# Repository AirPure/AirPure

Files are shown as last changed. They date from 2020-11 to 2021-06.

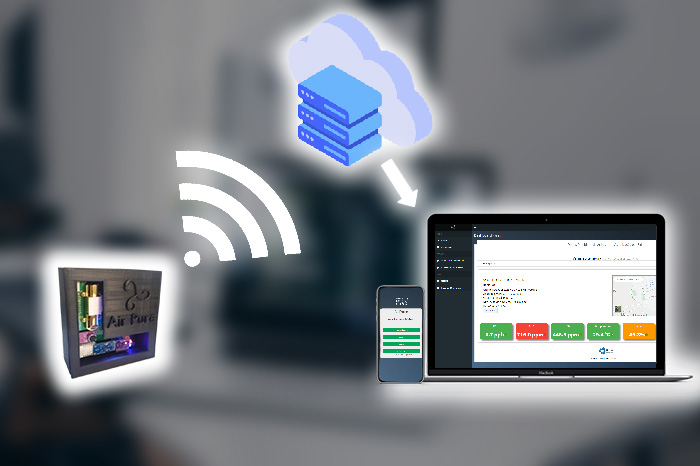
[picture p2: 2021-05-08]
Landing Page/assets/img/landing2.jpg

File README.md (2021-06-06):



[AirPure](https://sites.google.com/view/airpure/pagina-inicial?authuser=0) é um sistema embarcado para análise de qualidade do ar.

### Motivação
A qualidade do ar em ambientes internos torna-se uma preocupação em consequência do
aumento de construções de ambientes selados devido à climatização artificial. Apesar da
existência de legislações que exigem o monitoramento e controle da qualidade do ar, em
muitos locais há indícios de que essa prática não é aplicada, demonstrando a necessário
da implantação de um dispositivo que realize esse monitoramento de forma autônoma
e constante. Este trabalho apresenta o Air-pure, uma solução de Internet das Coisas
para o monitoramento da qualidade do ar em ambientes internos, que realiza a leitura
de temperatura, umidade relativa e concentrações de dióxido de carbono e Compostos
Orgânicos Voláteis Totais. A solução é organizada nas seguintes etapas: construção do
dispositivo físico, armazenamento e fusão dos dados na plataforma IoT ThingSpeakTM,
e página Web para apresentação dos dados aos usuários. Experimentos realizados em
ambientes climatizados artificialmente, mostram elevações na concentração de CO2 e
TVOC, que chegam a ultrapassar os limites recomendados. Os dados obtidos comprovam
a importância do monitoramento constante para avaliar situações diversas no ambiente e
a necessidade de ações, como a ventilação adequada, para melhoria da qualidade do ar e
consequentemente a saúde dos ocupantes.

### Tecnologias
* :white_check_mark: MQTT 
* :white_check_mark: IoT 
* :white_check_mark: ThingSpeak 
* :white_check_mark: WiFi 
* :white_check_mark: Over-the-Air Updates 
* :white_check_mark: ESP-NOW 
* :white_check_mark: Home Assistant 
* :white_check_mark: HTTP Protocol 

### Hardware
* :floppy_disk: ESP32 
* :floppy_disk: MHZ-14A 
* :floppy_disk: CCS811 
* :floppy_disk: DHT-22 
* :floppy_disk: MAX-9814 
* :floppy_disk: BH-1750

### Participantes do Projeto
* :bust_in_silhouette: Prof. Dr. Renato Bulcão Neto 
* :bust_in_silhouette: Prof. Dr. Iwens Sene Júnior 
* :bust_in_silhouette: Bruna Michelly  
* :bust_in_silhouette: Melyssa Mariana 
* :bust_in_silhouette: Isabela França 
* :bust_in_silhouette: Lucas Felipe 
* :bust_in_silhouette: Antonio Emílio

### Canais ThingSpeak
Canal 1 (1160801): [Clique Aqui](https://thingspeak.com/channels/1160801)</br>
Canal 2 (1167146): [Clique Aqui](https://thingspeak.com/channels/1167146)</br>
Canal 3 (1177969): [Clique Aqui](https://thingspeak.com/channels/1177969)</br>

### Como visualizar a aplicação
Para visualizar o website, [clique aqui.](https://airpurelanding.vercel.app/)

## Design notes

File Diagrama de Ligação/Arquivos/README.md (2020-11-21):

# AirPure
O AirPure é um sistema embarcado para análise de qualidade do ar.

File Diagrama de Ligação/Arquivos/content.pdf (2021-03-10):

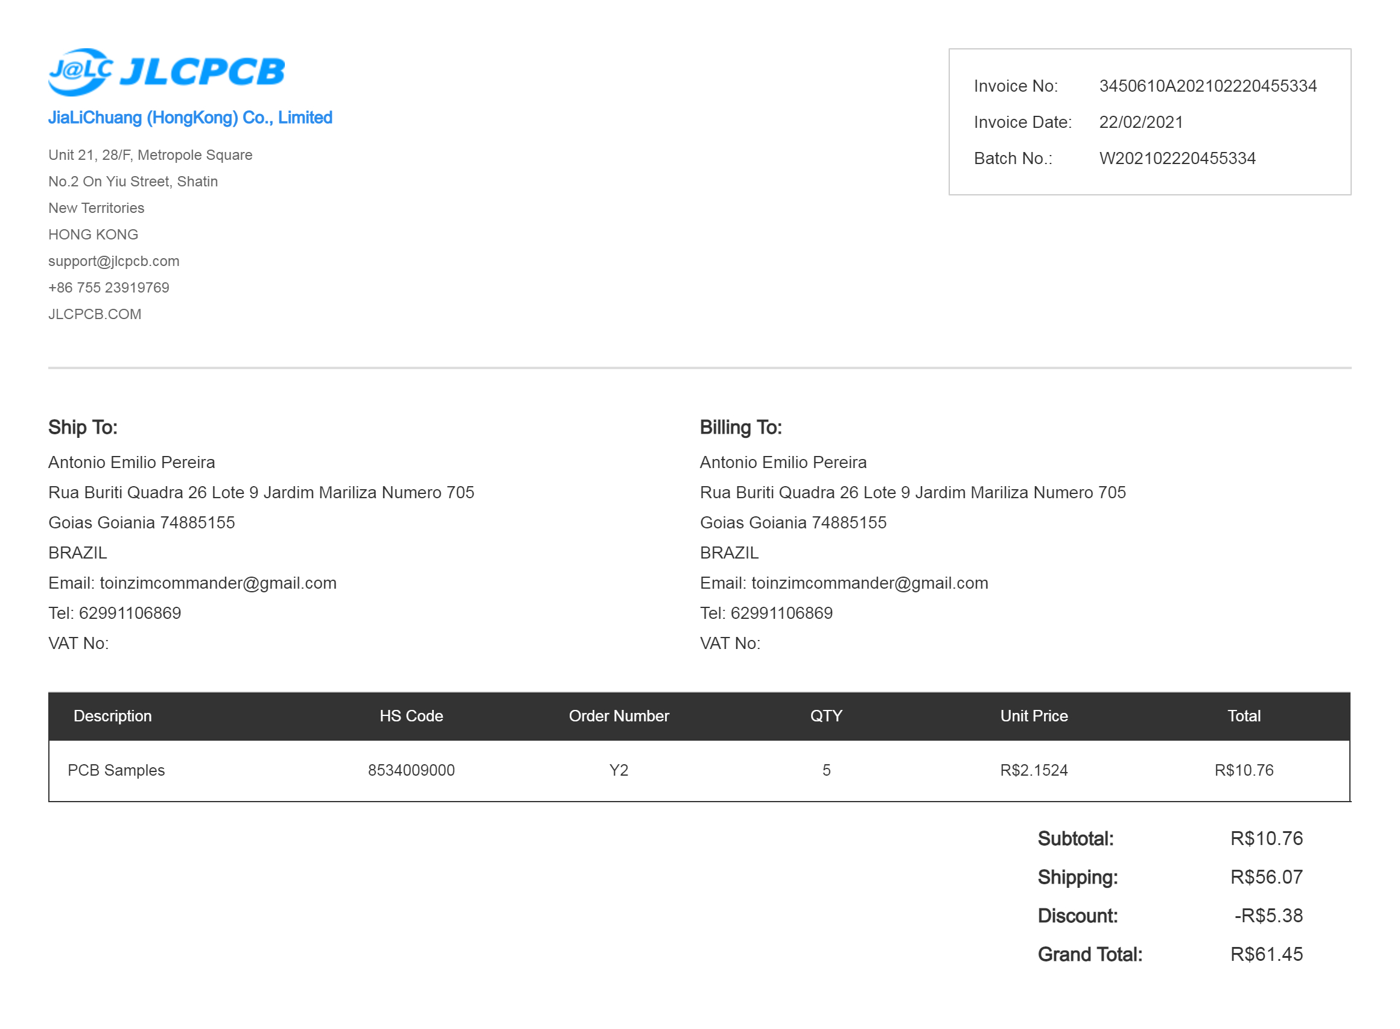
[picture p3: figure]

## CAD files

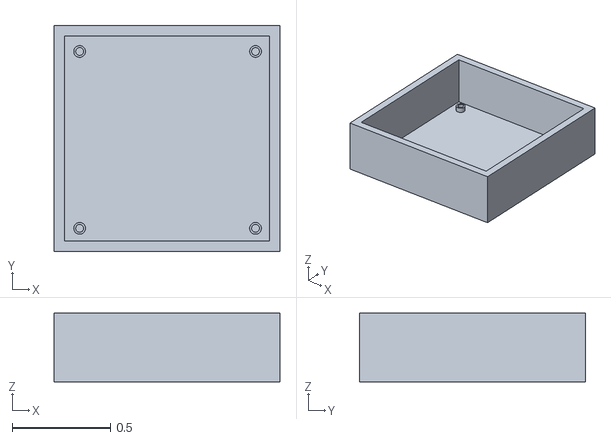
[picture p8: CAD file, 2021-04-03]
Diagrama de Ligação/Arquivos/TESTE23.stl
1.15 x 1.15 x 0.35

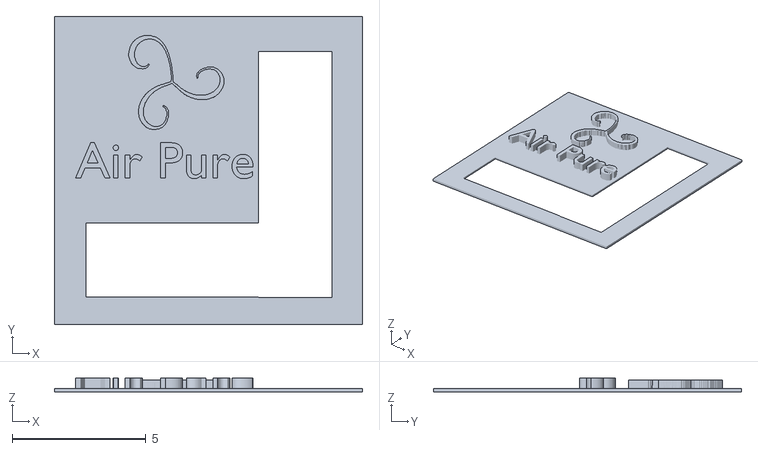
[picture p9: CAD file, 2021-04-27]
Diagrama de Ligação/Tampa.stl
11.5 x 11.5 x 0.515

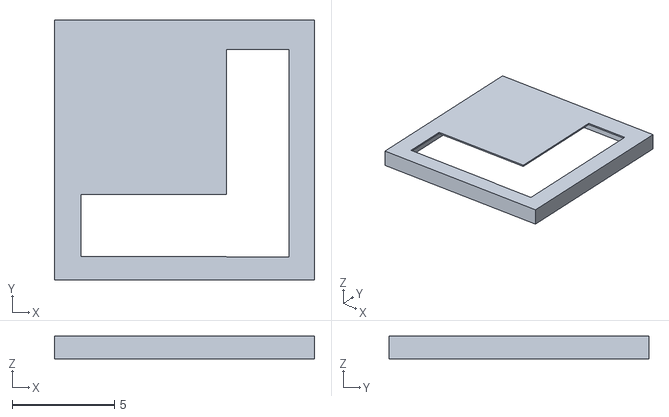
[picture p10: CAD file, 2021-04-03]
Diagrama de Ligação/Arquivos/TAMPASEMLOGO.stl
12.7 x 12.7 x 1.10

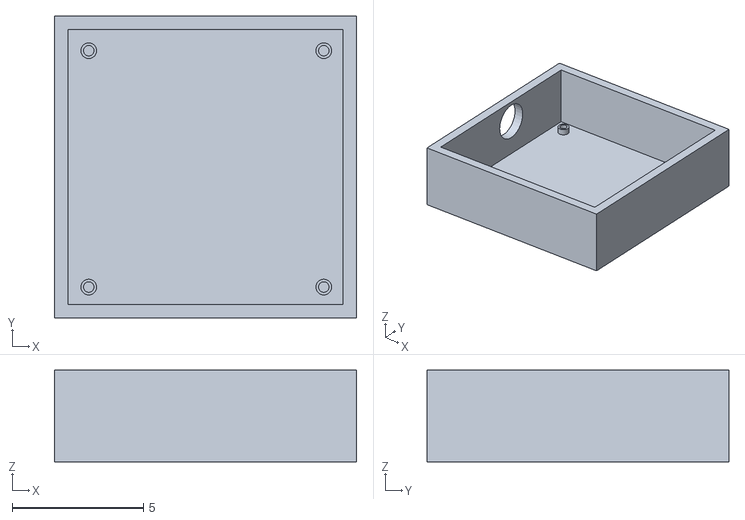
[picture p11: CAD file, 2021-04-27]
Diagrama de Ligação/Base.stl
11.5 x 11.5 x 3.50

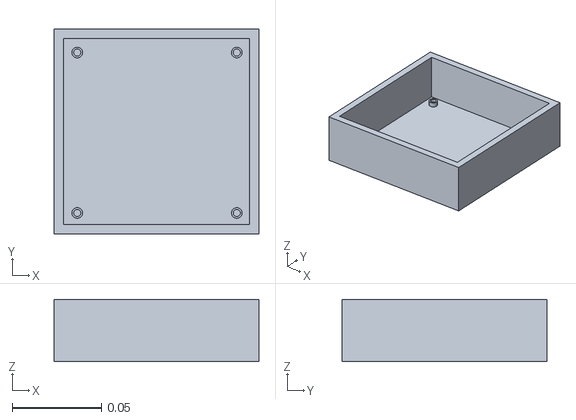
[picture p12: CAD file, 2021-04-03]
Diagrama de Ligação/Arquivos/TESTE1.stl
0.115 x 0.115 x 0.035

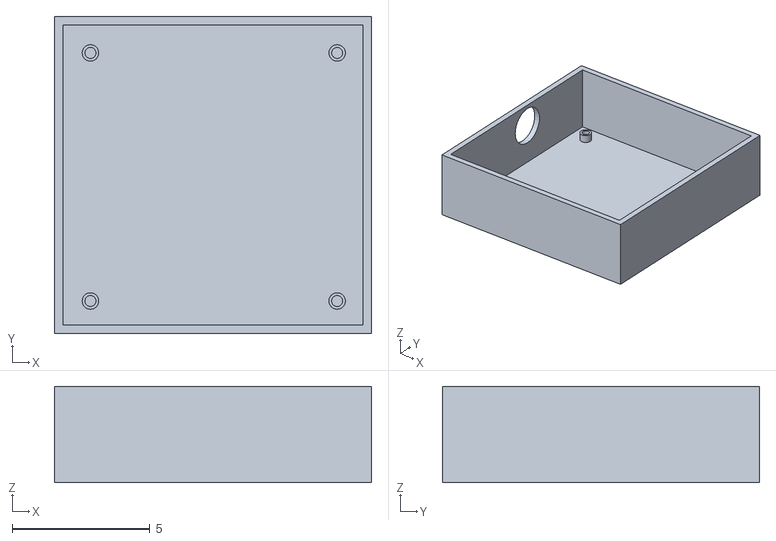
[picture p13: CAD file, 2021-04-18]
Diagrama de Ligação/COMPLETO2.stl
11.5 x 11.5 x 3.50

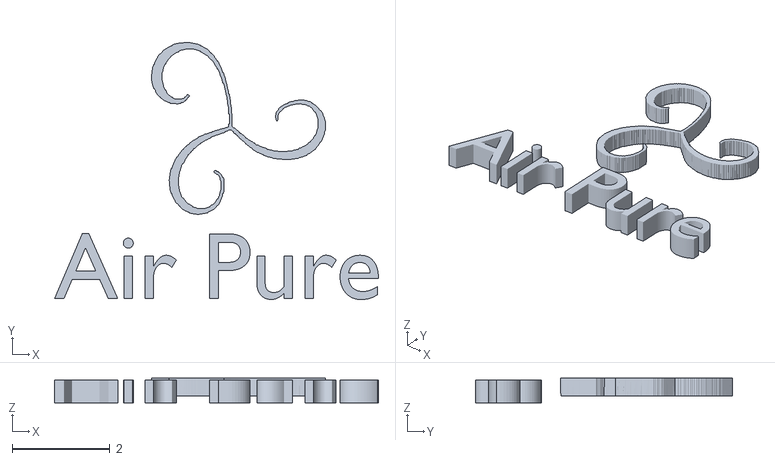
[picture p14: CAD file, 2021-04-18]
Diagrama de Ligação/LOGOAIRPURE.stl
6.63 x 5.26 x 0.511

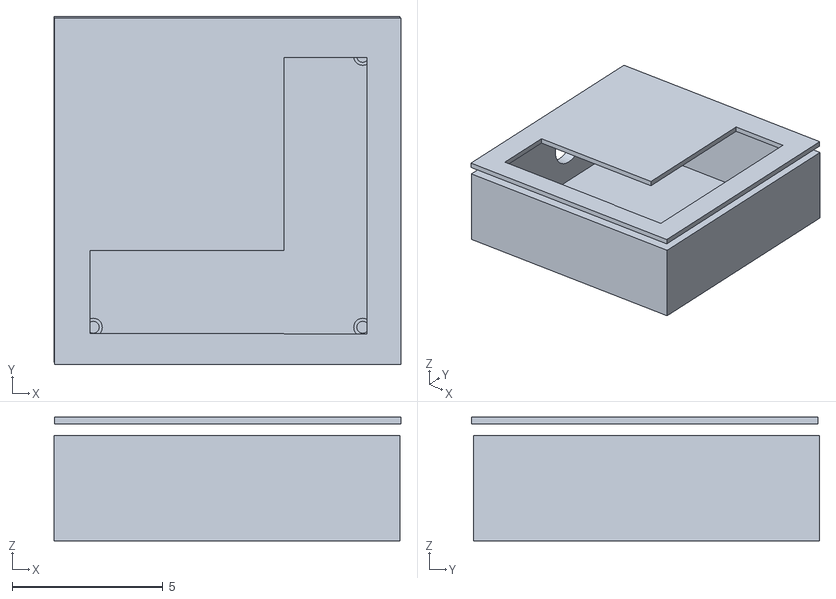
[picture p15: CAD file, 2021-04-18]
Diagrama de Ligação/COMPLETO.stl
11.5 x 11.6 x 4.11

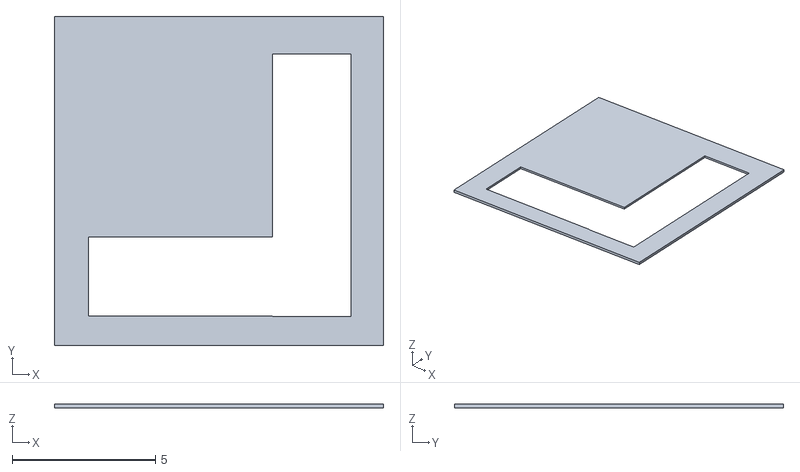
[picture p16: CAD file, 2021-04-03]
Diagrama de Ligação/Arquivos/TAMPASEMLOGO2.stl
11.5 x 11.5 x 0.128

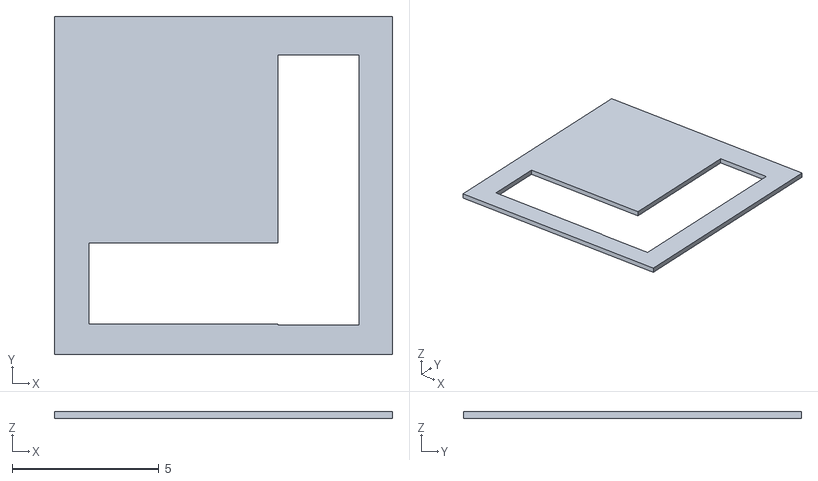
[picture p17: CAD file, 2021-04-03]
Diagrama de Ligação/TAMPA_OK.stl
11.5 x 11.5 x 0.231

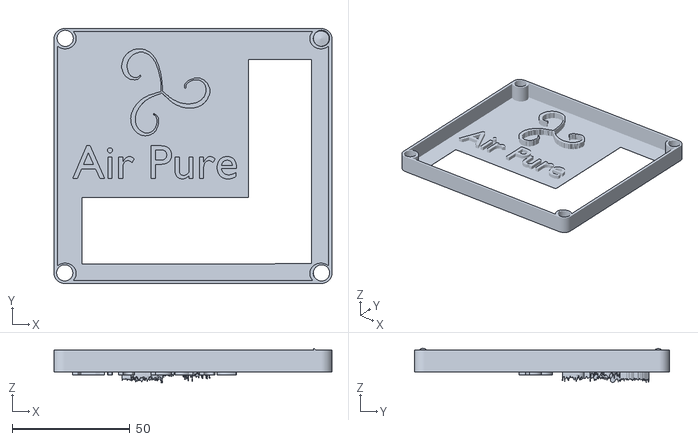
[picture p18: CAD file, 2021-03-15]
Diagrama de Ligação/Arquivos/tampa01.stl
118.2 x 108.5 x 14.7

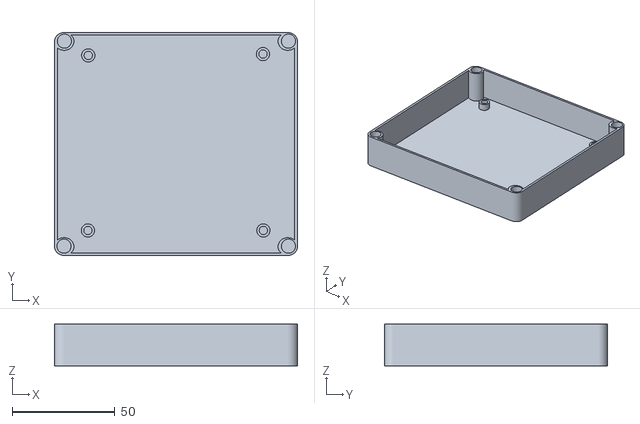
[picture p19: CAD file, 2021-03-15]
Diagrama de Ligação/Arquivos/base01.stl
118.2 x 108.5 x 20.3

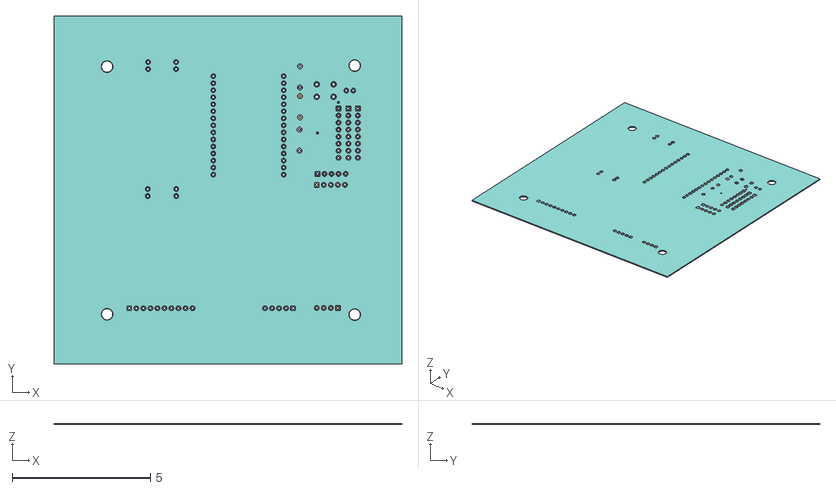
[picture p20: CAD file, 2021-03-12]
Diagrama de Ligação/Arquivos/PCB_AIRPURE_2021-03-10.obj
12.6 x 12.6 x 0.0503
Top
R2
R1
U1
J3
H2
J4
J5
J1
J2
J6
J7
J8
R3
SW1
LED1
IMPORTED_IMAGE
3.3V
SCL
SDA
LED_ESP
VOUT_DHT
TX2
GND
VOUT_MAX
33V
BUTTON
RX2
5V
LED1_2
Solder_Top
Core
Solder_Bottom

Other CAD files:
Diagrama de Ligação/Arquivos/TESTE233.stl
Diagrama de Ligação/Arquivos/BASE_AIRPURE.stl
Diagrama de Ligação/Arquivos/base02.stl
Diagrama de Ligação/Arquivos/OBJ_PCB_AIRPURE.obj
Diagrama de Ligação/Arquivos/OBJ_PCB_AIRPURE.stl
Diagrama de Ligação/Arquivos/PCB_AIRPURE_2021-02-21.dxf
Diagrama de Ligação/Arquivos/airpure_case.blend
Diagrama de Ligação/Arquivos/airpure_case.stl
Diagrama de Ligação/Arquivos/b100x100x25v1.stl
Diagrama de Ligação/Arquivos/hexagon_sheet_3.stl
Diagrama de Ligação/Arquivos/pcb_pcb_airpure_2021-03-10.stl
Diagrama de Ligação/Arquivos/sem título.stl
Diagrama de Ligação/Arquivos/untitled.blend
Diagrama de Ligação/Arquivos/untitled.stl
Diagrama de Ligação/Arquivos/untitledbase.stl
Diagrama de Ligação/FINAL_OK.blend
Diagrama de Ligação/TESTE1.blend

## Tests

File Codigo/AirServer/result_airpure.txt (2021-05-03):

5
5
6
5
10
21
1
1
5
2
3
6
3
1
1
1
1
1
1
1
1
1
1
1
1
1
1
1
1
1
1
1
1
5
5
5
5
5
5
1
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

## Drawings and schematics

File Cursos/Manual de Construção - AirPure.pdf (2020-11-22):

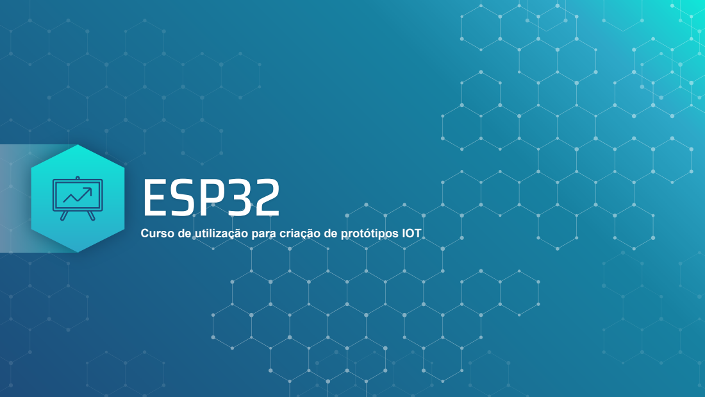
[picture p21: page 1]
ESP32

Curso de utilização para criação de protótipos IOT

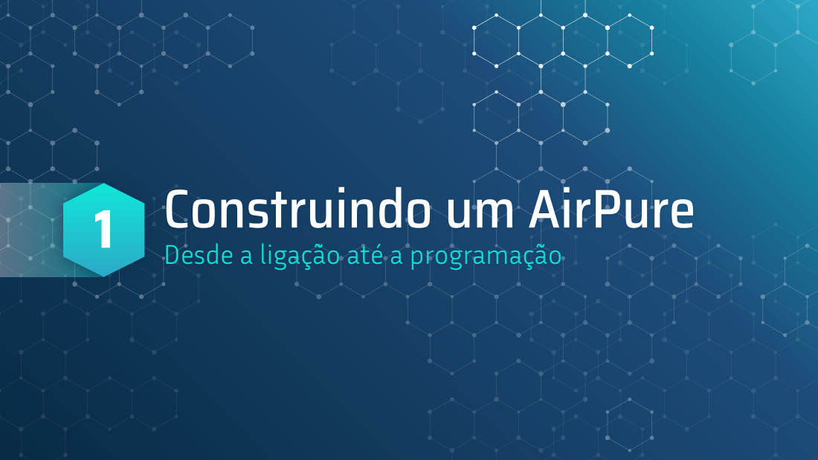
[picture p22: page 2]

Construindo um AirPure
Desde a ligação até a programação 1

# Diagrama de ligações

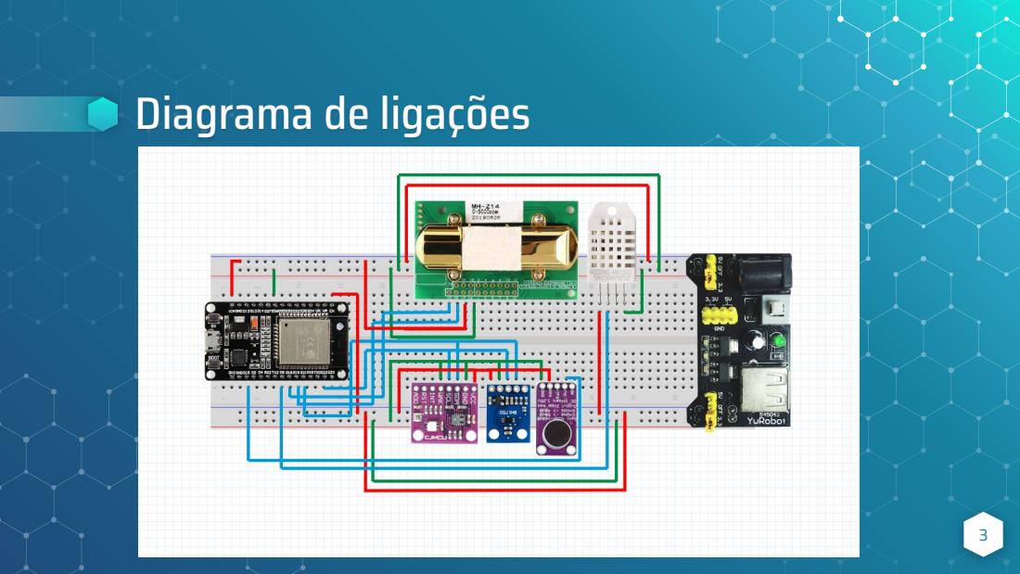
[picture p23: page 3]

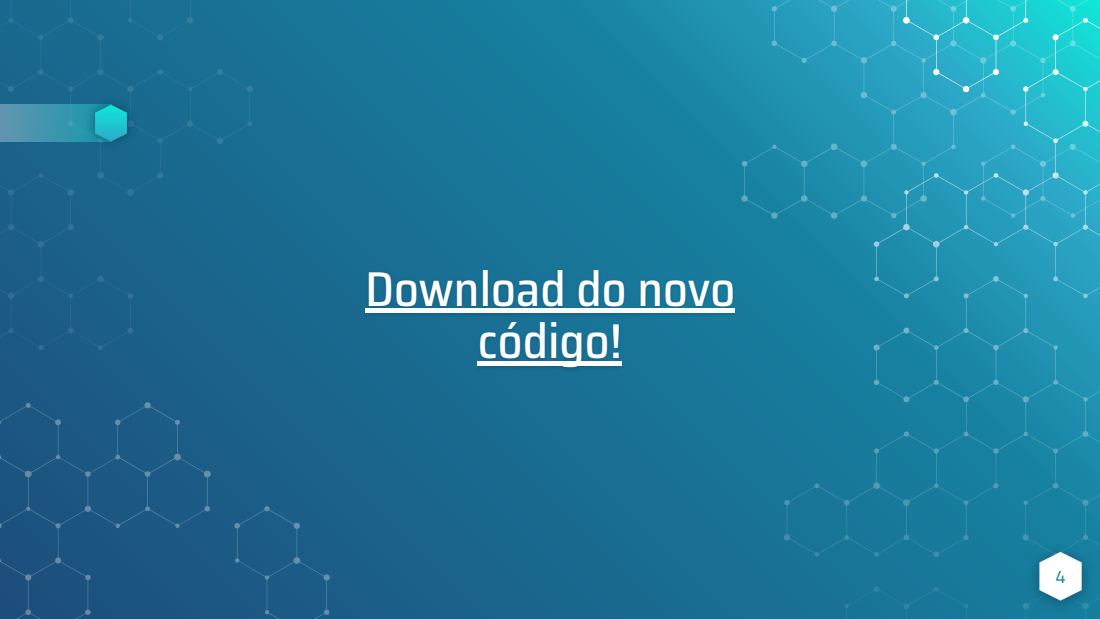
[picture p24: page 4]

Download do novo (https://drive.google.com/file/d/1TJgL_6C4kQ0yvQ0MD830oPwlq83Xvipd/view?usp=sharing)
código! (https://github.com/AirPure/AirPure)

# Bibliotecas necessária

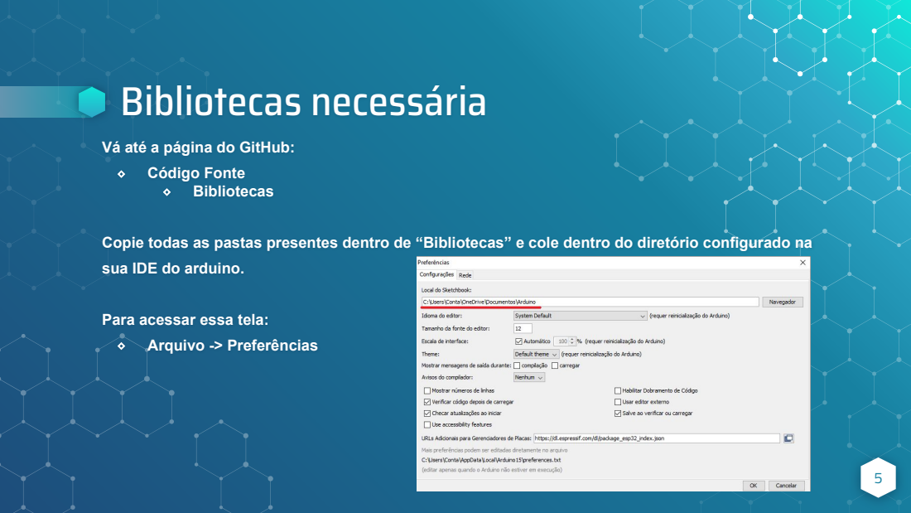
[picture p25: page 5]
Código Fonte; Bibliotecas; Arquivo -> Preferências

Vá até a página do GitHub:

Copie todas as pastas presentes dentro de “Bibliotecas” e cole dentro do diretório configurado na
sua IDE do arduino.

Para acessar essa tela:

# Configurando as credenciais

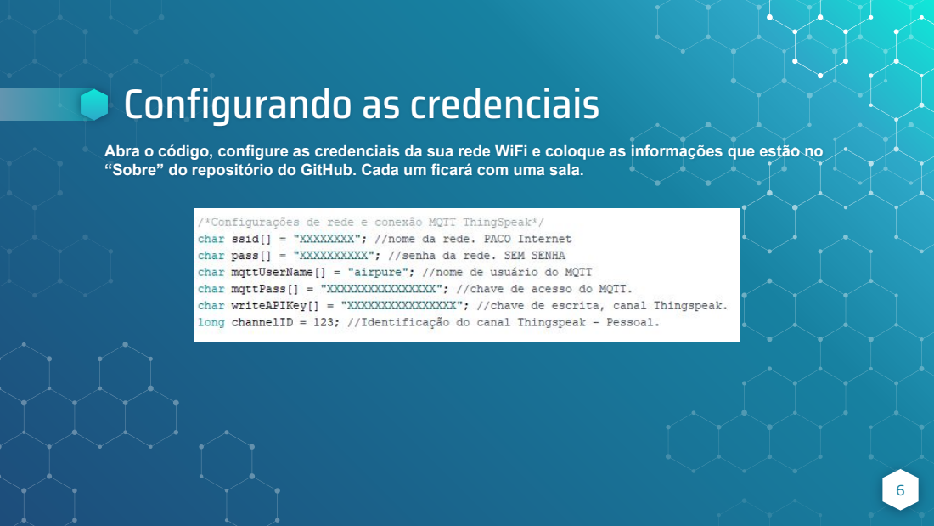
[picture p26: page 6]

Abra o código, configure as credenciais da sua rede WiFi e coloque as informações que estão no
“Sobre” do repositório do GitHub. Cada um ficará com uma sala.

# Grave o código no seu AirPure

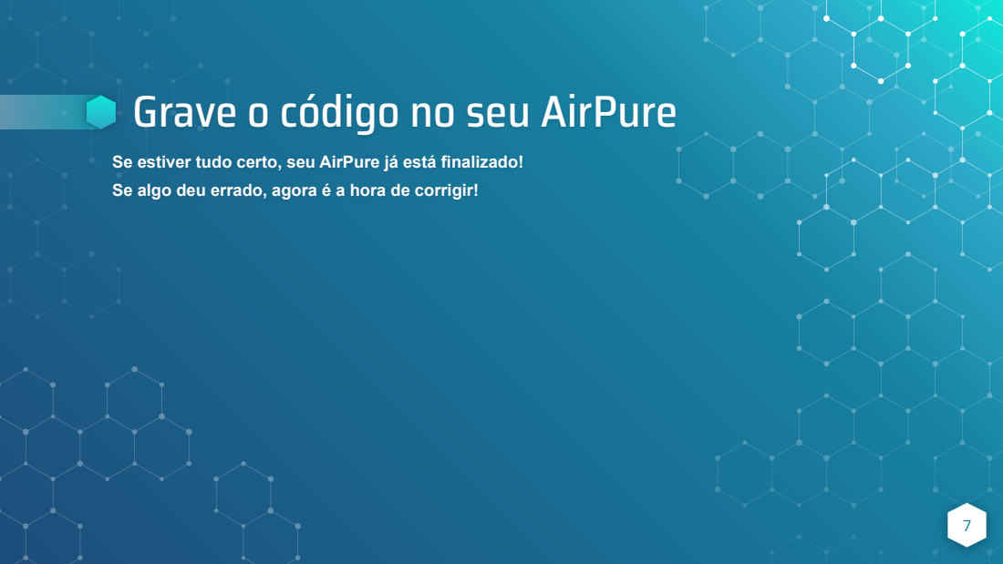
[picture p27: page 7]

Se estiver tudo certo, seu AirPure já está finalizado!
Se algo deu errado, agora é a hora de corrigir!

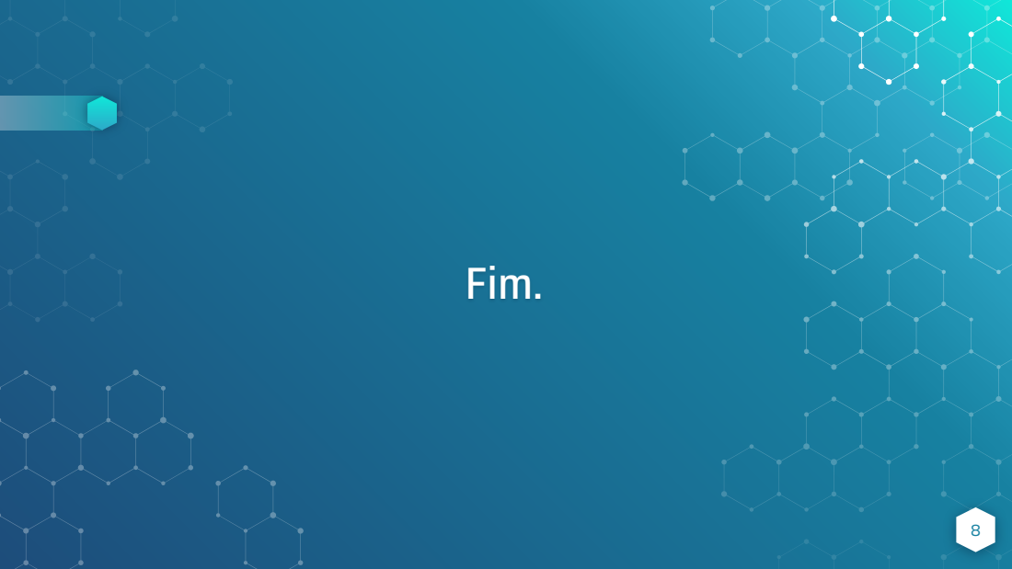
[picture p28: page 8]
Fim.

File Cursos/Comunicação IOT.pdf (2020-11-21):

Melyssa Mariana
melyssa.mariana32@gmail.com
Tecnologias de
comunicação iot:

Da teoria à prática

# IOT x embarcados

1

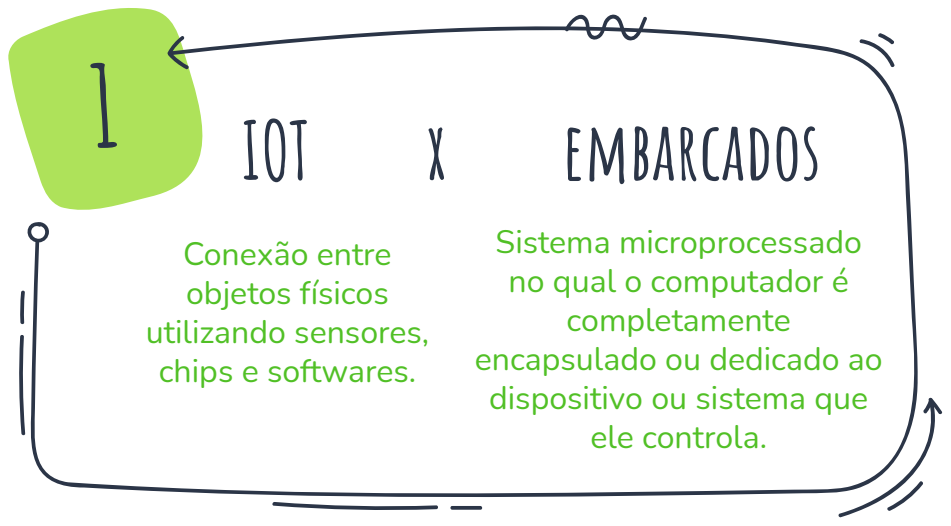
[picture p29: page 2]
Conexão entre objetos físicos utilizando sensores, chips e softwares.

Sistema microprocessado
no qual o computador é
completamente
encapsulado ou dedicado ao
dispositivo ou sistema que
ele controla.

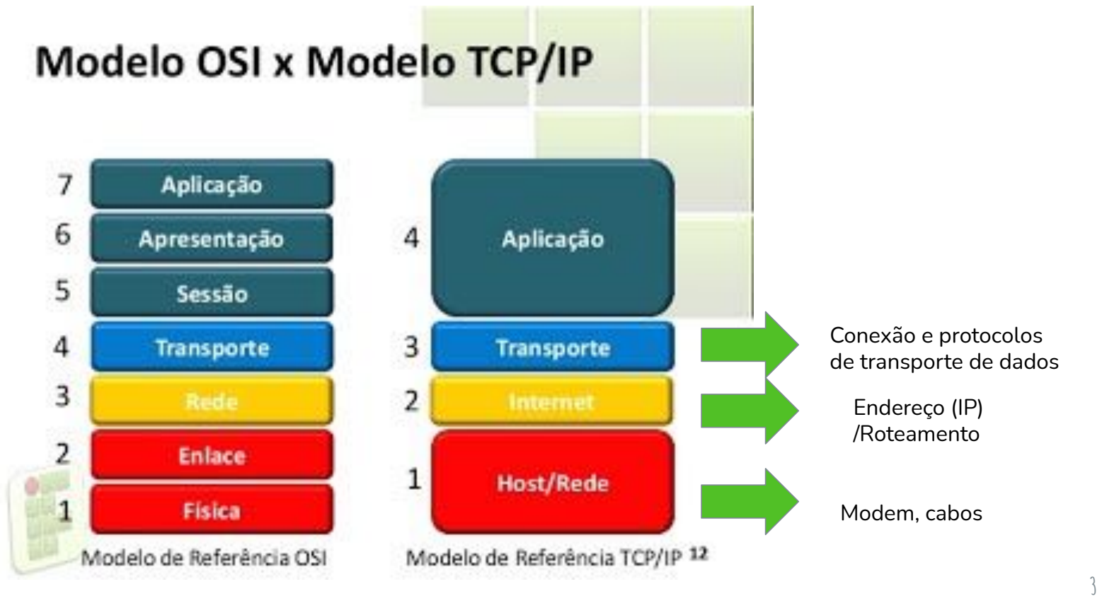
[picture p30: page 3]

3

Modem, cabos

Endereço (IP)
/Roteamento

Conexão e protocolos
de transporte de dados

## Capacidade de um canal de comunicação

## O que são Protocolos?

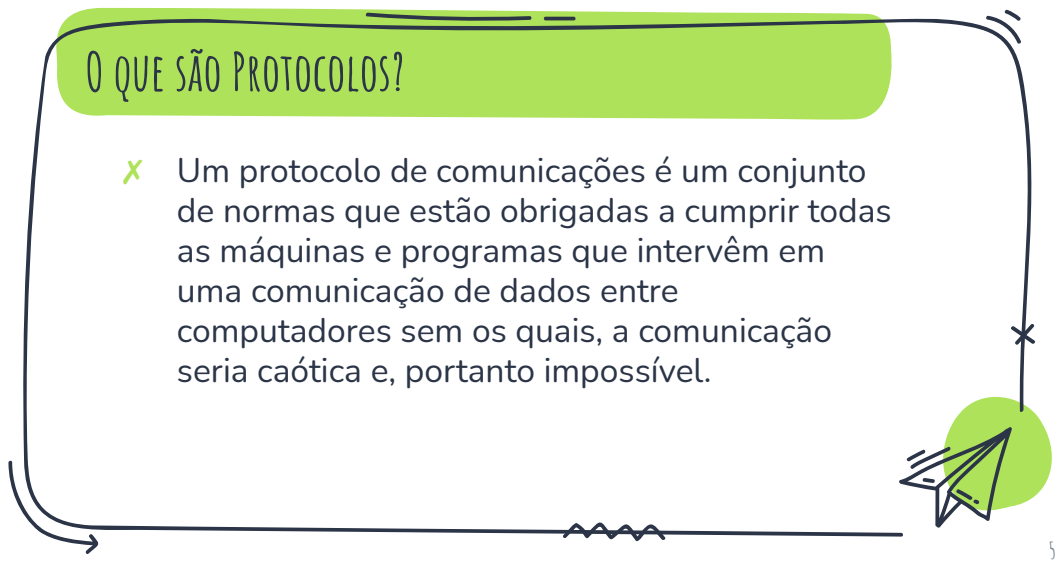
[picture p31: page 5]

✗ Um protocolo de comunicações é um conjunto
de normas que estão obrigadas a cumprir todas
as máquinas e programas que intervêm em
uma comunicação de dados entre
computadores sem os quais, a comunicação
seria caótica e, portanto impossível.

Standard | 802.11 | Bluetooth | IEEE 802.15.1 | 802.15.4 IEEE | IEEE 802.16 | Z-Wave Alliance | GSM GPRS | LoRaWA R1.0 | ECMA-340 and ISO/IEC 18092
Tipo de rede: | LAN | PAN | LAN | LAN | MAN | LAN | MAN | LAN | -
Topologia | Estrela | Estrela | Mesh, Estrela, Árvore | Mesh, Estrela | Mesh | Mesh | Mesh | Estrela | Par a par
Frequencia | 5–60 GHz | 2.4 GHz | 2.4 GHz | 2.4 GHz | 2.5-GHz 3.5-GHz 5.8-GHz | 908.42 MHz | 2.4 GHz | 868/900 MHz | 13.56 MHz
Consumo de energia | Baixo Alto | Baixo | Muito baixo | Muito baixo | Alto | Muito baixo | Alto | Muito Baixo | Médio
Taxa de envio de dados | 1.3 Gbps | 1–24 Mb/s | 250 kb/s | 300 kb/s | 11-100mb/s | 40kb/s | 0.1–1 Gb/s | 0.3–50 Kb/s | 424 Kb/s
Alcance | 100m | 8–10 m | 10-20m | 10-20m | 50km | 100m | Área do sinal | <30 Km | 10cm
Tipo de aplicacao | Qualquer dispositivo com capacidade de conexão | Rede para troca de dados | Sensor network de automação industrial | Sensor network de automação industrial | Conexão de Internet de marca ampla na área metropolitana | Automação residencial | Celulares | Smart cities | Cartão de crédito/ônibus
Tamanho da rede | Médio | Pequena | Muito grande | Muito grande | Grande | Grande | Muito grande | Médio | Muito pequena
Custo | Alto | Baixo | Médio | Baixo - Médio | Alto | Baixo - Médio | Médio | Médio | Baixo

## 1- NFC

✗ | NFC é uma sigla para “Near Field Communication”
✗ | tecnologia de troca de dados sem fio por aproximação entre dois dispositivo
✗ | - Leitura e gravação: tendo como base a comunicação passiva, permite leitura ou alteração de dados existentes em um dispositivo NFC, como um receptor que desconta créditos registrados em um cartão de viagens (como o Bilhete Único da cidade de São Paulo);
✗ | - Peer-to-peer: é um modo para troca bidirecional de informações entre os dois dispositivos, ou seja, cada um pode tanto receber quanto enviar dados para o outro. Pode ser útil, por exemplo, para a troca de arquivos entre dois smartphones;
✗ | - Emulação de cartão: neste modo, o dispositivo NFC pode se passar por um cartão inteligente, de forma que o aparelho leitor não consiga distinguir um do outro.

✗
7

## 1- NFC

## 2- Zigbee

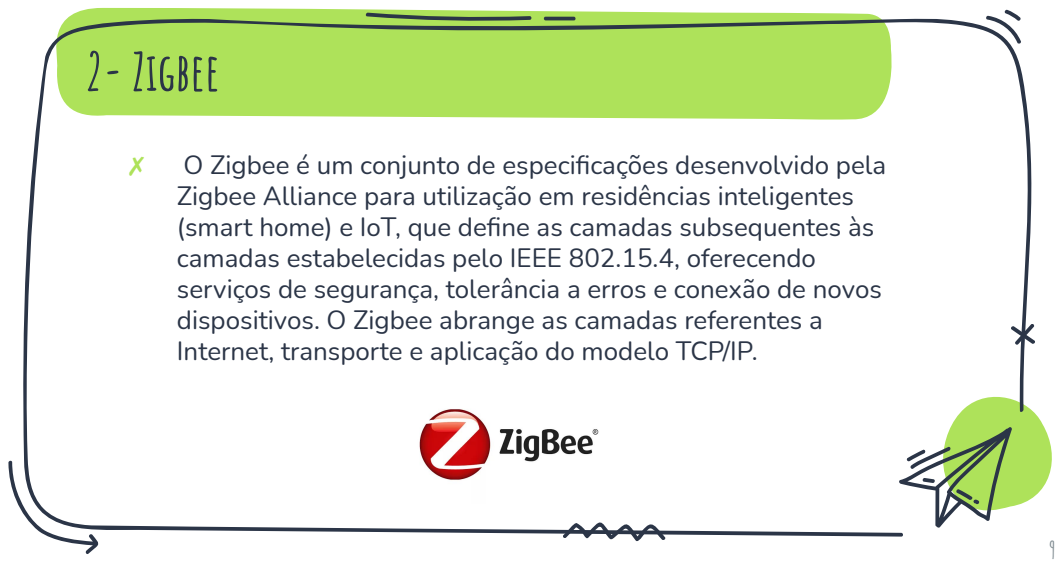
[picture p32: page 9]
O Zigbee é um conjunto de especificações desenvolvido pela

Zigbee Alliance para utilização em residências inteligentes
(smart home) e IoT, que define as camadas subsequentes às
camadas estabelecidas pelo IEEE 802.15.4, oferecendo
serviços de segurança, tolerância a erros e conexão de novos
dispositivos. O Zigbee abrange as camadas referentes a
Internet, transporte e aplicação do modelo TCP/IP.

## 3- WiFI


✗ Wireless Fidelity,
✗ WLAN (Wireless Local Area Network).
✗ Protocolo 802.11 (a, b, g e n,)

## 4- WiFI

## 5- Bluetooth


Bluetooth é uma especificação de rede sem fio (https://pt.wikipedia.org/wiki/Wireless) de âmbito

pessoal (Wireless personal area networks | – PANs)
consideradas do tipo PAN (https://pt.wikipedia.org/wiki/Rede_de_%C3%A1rea_pessoal) ou mesmo WPAN

## 6- GPRS

Gerais de Pacote por Rádio. GPRS é uma tecnologia que tem
o objetivo de aumentar as taxas de transferência de dados
entre celulares, facilitando a comunicação e o acesso a redes.

## 7- Lora

LoRa (Long; Range) é uma tecnologia de rede de

área ampla de baixa potência. Baseia-se em
técnicas de modulação de espectro de propagação

derivadas da tecnologia | chirp spread spectrum (https://pt.wikipedia.org/w/index.php?title=Chirp_spread_spectrum&action=edit&redlink=1)
(CSS).

## 7- Lora

✗ Baixo consumo de energia
✗ Possibilidade de montar sua própria rede
✗ Solução para IoT em ambientes remotos
✗ Frequências baixas (433~968MHz)

✗ Longo alcance (Geralmente 2~7Km)
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


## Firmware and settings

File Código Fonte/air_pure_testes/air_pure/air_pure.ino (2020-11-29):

/*Bibliotecas*/
#include <PubSubClient.h>
#include <WiFiManager.h>         
#include <BH1750.h>
#include <DHT.h>
#include <WiFi.h>
#include <SPI.h>
#include <Adafruit_CCS811.h>


/*Definir os pinos dos sensor*/
#define dhtPin 4 //Sensor de temperatura e umidade - DHT22.
#define dbMeterPin 34 //Entrada analógica do sensor de ruído - MAX9814
#define RXD2 16 //Sensor de CO2 - MH-Z14A.
#define TXD2 17 //Sensor de CO2 - MH-Z14A.
BH1750 lightMeter (0x23); //Sensor de luminosidade - BH1750 (Addr: 0x23)


/*Configuração de sensores.*/
//DHT22 - Temperatura e Umidade.
#define dhtType DHT22 //Tipo do sensor DHT.
DHT dht(dhtPin, dhtType); //Objeto sensor de temperatura e umidade
//CSS811 - TVOC
Adafruit_CCS811 ccs; //Objeto sensor de TVOC.

//Definir variaveis globais.
float temp; //Temperatura em graus celsius.
float umid; //Umidade relativa.
uint16_t lux; //Valor em Lux referente à luminosidade.
float eco2; //Equivalente de Dióxido de carbono.
float voc; //Total de compostos organicos voláteis.
float valorCO2; //Dióxido de carbono. 
float dbLevel; //Valor em DB de ruído do ambiente


/*Configurações de rede e conexão MQTT ThingSpeak*/
char ssid[] = "Antonielli"; //nome da rede. PACO Internet
char pass[] = "12345678"; //senha da rede. SEM SENHA
char mqttUserName[] = "airpure"; //nome de usuário do MQTT
char mqttPass[] = "0QIMS6VELRQUUC0A"; //chave de acesso do MQTT.
char writeAPIKey[] = "EB6J5ATU4ETP7984"; //chave de escrita, canal Thingspeak.
long channelID = 1167146; //Identificação do canal Thingspeak - Pessoal.


/*Definir identificação de cliente, randomico.*/
static const char alphanum[] = "0123456789""ABCDEFGHIJKLMNOPQRSTUVWXYZ""abcdefghijklmnopqrstuvwxyz";

WiFiClient client; //Inicializar cliente wifi

//Inicializar a biblioteca pubsubclient e definir o broker MQTT thingspeak.
PubSubClient mqttClient(client);
const char* server = "mqtt.thingspeak.com";

unsigned long lastConnectionTime = 0; //Tempo da última conexão.
const unsigned long postingInterval = 20000L; //Tempo de postagem, 20 segundos.
const int sampleWindow = 50; // Janela de amostragem em mS (50 mS = 20Hz)
unsigned int sample;  //Variável referente a leitura do sensor de ruído

void setup() {
  Serial.begin(115200); //Iniciar porta serial - USB.
  Serial2.begin(9600, SERIAL_8N1, RXD2, TXD2); //Iniciar porta serial - UART.
  int status = WL_IDLE_STATUS; //Estado da conexão wifi.

  //Inicializar sensor CCS811.
  if(!ccs.begin()){
    Serial.println("Falha ao iniciar o CCS811! Checar conexão dos fios.");
    ESP.restart();
  }
  
  dht.begin(); //Inicializar DHT22.
  lightMeter.begin(); //Inicilizar o BH1750.

  
  pinMode(dhtPin, INPUT); //Configurar modo dos pinos do DHT.
   pinMode(dbMeterPin, INPUT); //Configurar modo dos pinos do MAX9814.
  

    while(status != WL_CONNECTED){
    Serial.println("Tentando se conectar...");
    status = WiFi.begin(ssid, pass); //Conectar a rede WiFi WPA/WPA2.
    delay(1000);
    }
/*
    //WiFiManager
    WiFiManager wifiManager;
    wifiManager.setTimeout(180);  //Timeout de 3 minutos
  
    //Deixa a configuração quando esta é finalizada
    wifiManager.setBreakAfterConfig(true);
  
  
    //Tenta conectar com o último SSID conhecido
    //Se não conseguir, abre um AP para ser configurado
    //SSID do AP: AiPure  Senha: 12345678
    //and goes into a blocking loop awaiting configuration
    if (!wifiManager.autoConnect("AirPure", "12345678")) {
      Serial.println("Falhou para se conectar... Reiniciando.");
      delay(3000);
      ESP.restart();
      delay(5000);
    }
*/
    
  Serial.print("Conectado ao WiFi: "); //Imprimir nome da rede conectada.
  Serial.println(ssid);
  
  mqttClient.setServer(server, 1883); //Configurar Broker MQTT - ThingSpeak.
}

void loop() {
  //Conectar MQTT.
  if(!mqttClient.connected()){
    reconnect();
    }

  mqttClient.loop(); //Manter conexão MQTT.

  while(1){
    lightMeter.begin(); //Inicilizar o BH1750.
    mqttpublish();
    delay(1000);
  }

}

//Faz o map de valores, retornando floats (Necessário pois o map nativo retorna apenas inteiros).
float mapfloat(float x, float in_min, float in_max, float out_min, float out_max)
{
  return (x - in_min) * (out_max - out_min) / (in_max - in_min) + out_min;
}


float readDb(){

   unsigned long startMillis= millis();  // Inicio da janela de amostragem
   unsigned int peakToPeak = 0;   // Nível pico a pico

   unsigned int signalMax = 0;  //Valor análogico mínimo
   unsigned int signalMin = 1024;  //Valor analógico máximo

   // Coleta dados por aproximadamente 50ms
   while (millis() - startMillis < sampleWindow)
   {
      sample = analogRead(dbMeterPin); //Faz a leitura analógica do MAX9814
      if (sample < 1024) 
      {
         if (sample > signalMax)
         {
            signalMax = sample;  // Salva apenas os valores máximos
         }
         else if (sample < signalMin)
         {
            signalMin = sample;  // Salva apenas os valores mínimos
         }
      }
   }
   peakToPeak = signalMax - signalMin;  // Máximo - Mínimo = Amplitude pico a pico
   double volts = (peakToPeak * 3.0) / 1024;  // Converte para um valor de tensao aproximado

   
   
   if (volts <= 1000){ //Valor máximo possível 
      float value = mapfloat(volts, 0.00, 3.00, 37.00, 82.00);
      return value;
    
   } else {
      return 37;
   }

}


//Leitura da concentração de gás - MH-Z14A.
float leituraGas(){

  const byte comando[9] =  {0xFF, 0x01, 0x86, 0x00, 0x00, 0x00, 0x00, 0x00, 0x79}; //Comando de leitura da concentração de gás.
  byte resposta[9]; //Armazena a resposta do comando de leitura.

  //Escrever comando de leitura.
  for(int i = 0; i<9; i++){
    Serial2.write(comando[i]);
    }

  delay(30);

  //Ler retorno do comando de leitura.
  if(Serial2.available()){
    for(int i=0; i<9; i++){
      resposta[i] = Serial2.read();
      }
    int alto = (int)resposta[2];
    int baixo = (int)resposta[3];

    float CO2 = ((alto*256)+baixo); //Concentração de CO2 em ppm, referência datasheet.

    return CO2;
  }
}

//Conectar ao Broker MQTT.
void reconnect(){
  char clientID[9]; //Identificação do cliente.

  //Gerar ID do cliente.
  while(!mqttClient.connected()){
    Serial.print("Tentando conexão MQTT...");
    for(int i=0; i<8; i++){
      clientID[i] = alphanum[random(100)];
      }
  clientID[8] = '\0';

  //Iniciar conexão MQTT.
  if(mqttClient.connect(clientID, mqttUserName, mqttPass)){
    Serial.println("Conectado.");
    }else{
      Serial.print("Failed, rc= ");
      /*Verificar o porque ocorreu a falha.*/
      //Ver em: https://pubsubclient.knolleary.net/api.html#state explicação do código da falha.
      Serial.print(mqttClient.state());
      ESP.restart();
      }
   }
 }

 //Publicar dados ThingSpeak.
 void mqttpublish(){
  delay(100);
  dbLevel = readDb();
  delay(100);
 //Leitura dos valores.
  //DHT22 - Temperatura e Umidade.
  temp = dht.readTemperature(); //Ler temperatura - DHT22.
  umid = dht.readHumidity(); //Ler umidade - DHT22.
  lux = lightMeter.readLightLevel(); //Ler luminosidade - BH1750.


  //CCS811 - TVOC
   if(ccs.available()){
    if(!ccs.readData()){
      eco2 = ccs.geteCO2(); //Ler eCO2 - CCS811.
      voc = ccs.getTVOC(); //Ler TVOC - CCS811.
    }else{
      Serial.println("Erro de leitura CCS811!");
      return;
    }
  }

  valorCO2 = leituraGas(); //Concentração de CO2 - MH-Z14A.
  
  //String de dados para enviar a Thingspeak.
  String dados = String("field1=" + String(temp, 2) + "&field2=" + String(umid, 2) + "&field3=" +String(eco2, 2)+ "&field4=" +String(voc, 2)+ "&field5=" + String(valorCO2)+ "&field6=" + String(lux,5)+ "&field7=" + String(dbLevel,2));
  int tamanho = dados.length();
  char msgBuffer[tamanho];
  dados.toCharArray(msgBuffer,tamanho+1);
  Serial.println(msgBuffer);

  //Cria uma String de tópico e publica os dados na Thingspeak.
  String topicString = "channels/" + String(channelID) + "/publish/"+String(writeAPIKey);
  tamanho = topicString.length();
  char topicBuffer[tamanho];
  topicString.toCharArray(topicBuffer, tamanho+1);
  if(millis() - lastConnectionTime > postingInterval){
      Serial.println("Hora de enviar!");
      int r = mqttClient.publish(topicBuffer, msgBuffer); //Publicar dados.
      if (r){
        Serial.println("Envio feito com sucesso!");
      } else {
        Serial.println("Envio não foi feito!");
      }
      lastConnectionTime = millis();
  }

  }

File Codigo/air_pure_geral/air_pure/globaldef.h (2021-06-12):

/*
O AirPure é um dispositivo embarcado para análise de qualidade do ar.
Seu código atualmente é mantido por professores e estudantes da UFG.
Confira nosso repositório no GitHub: https://github.com/AirPure/AirPure
*/



/*Definição*/
#define dhtPin 4 //Sensor de temperatura e umidade - DHT22.
#define dbMeterPin 34 //Entrada analógica do sensor de ruído - MAX9814
#define RXD2 16 //Sensor de CO2 - MH-Z14A.
#define TXD2 17 //Sensor de CO2 - MH-Z14A.
#define uS_TO_S_FACTOR 1000000  /* Fator de conversao de microsegundos para segundos */
#define TIME_TO_SLEEP  60        /* Tempo de sleep do ESP32 em segundos */
#define BTKEN "1403262308:AAF1zrbdz0-rEyXTdJUdT20MhA0eBpCT_TQ"  // Token do seu BOT do telegram.
#define CHAT_ID "1248387297"  //Seu ID no telegram.
#define dhtType DHT22 //Tipo do sensor DHT.
#define CCS811_ADDR 0x5A //Endereço I2C padrão
#define maxRecords 100
#define mqtt_server "airpure-home-assistant.duckdns.org" //Endereço MQTT Home Assistant
#define gatewayNodeMode 0 //Modo Node
#define isGateway 0 //Modo GW
#define outputPin 25 //Contador de pessoas
#define btn01 32  //Contador de pessoas
#define btn02 12 //Contador de pessoas
#define V_FIRMWARE 7  //Versão do Firmware
#define PORTA_TRIGGER1   13
#define PORTA_ECHO1      14
#define PORTA_TRIGGER2   4
#define PORTA_ECHO2      5
#define ON_IDLE 1
#define WORKING 2
#define EAP_IDENTITY "antoniopereira@discente.ufg.br" //if connecting from another corporation, use identity@organisation.domain in Eduroam 
#define EAP_PASSWORD "xxxxxx" //your Eduroam password
#define EAP_ANONYMOUS_IDENTITY "antoniopereira@discente.ufg.br"
#define WIFI 3
#define LOOKING_FOR_WIFI
#define ledPin 15
#define ledPin2 2

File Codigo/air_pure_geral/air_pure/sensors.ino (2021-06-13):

/*
O AirPure é um dispositivo embarcado para análise de qualidade do ar.
Seu código atualmente é mantido por professores e estudantes da UFG.
Confira nosso repositório no GitHub: https://github.com/AirPure/AirPure
*/


/*Leitura da concentração de gás - MH-Z14A.*/
float leituraGas() {
  Serial.println("Lendo CO2.");
  const byte comando[9] = { 0xFF, 0x01, 0x86, 0x00, 0x00, 0x00, 0x00, 0x00,
      0x79 }; //Comando de leitura da concentração de gás.
  byte resposta[9]; //Armazena a resposta do comando de leitura.

//Escrever comando de leitura.
  for (int i = 0; i < 9; i++) {
    Serial2.write(comando[i]);
  }
  delay(30);
//Ler retorno do comando de leitura.
  if (Serial2.available()) {
    for (int i = 0; i < 9; i++) {
      resposta[i] = Serial2.read();
    }
    int alto = (int) resposta[2];
    int baixo = (int) resposta[3];
    float CO2 = ((alto * 256) + baixo); //Concentração de CO2 em ppm, referência datasheet.

    if (CO2 > 10000) {    //Range máximo do sensor e 10000ppm
      CO2 = 400; //Caso o valor bata o fundo de escala (comum no processo de warm-up do sensor), envia o valor base de CO2 em ppm.
    }

    Serial.println("(OK)");

    return CO2;
  }
}

/*Leitura de luminosidade*/
float readLux() {

  Serial.println("Iniciando o BH1750...");
  r = lightMeter.begin(); //Inicilizar o BH1750.
  if (r)
    Serial.println("BH1750 iniciado!");
  else {
    Serial.println("BH1750 não foi iniciado!");
    lux = 0;
  }

  delayTimes(1);

  //BH1750 - Luminosidade
  Serial.println("Lendo luminosidade.");
  lux = lightMeter.readLightLevel(); //Ler luminosidade - BH1750.
  Serial.println("(OK)");
}

/*Leitura de ruído*/
float readDb() {

  Serial.println("Lendo valor de ruido.");
  unsigned long startMillis = millis();  // Inicio da janela de amostragem
  unsigned int peakToPeak = 0;   // Nível pico a pico
  unsigned int signalMax = 0;  //Valor análogico mínimo
  unsigned int signalMin = 1024;  //Valor analógico máximo
  double voltsTotal = 0;

  for(int i = 0; i < 10; i ++){
  // Coleta dados por aproximadamente 50ms
  while (millis() - startMillis < sampleWindow) {
    sample = analogRead(dbMeterPin); //Faz a leitura analógica do MAX9814
    if (sample < 1024) {
      if (sample > signalMax) {
        signalMax = sample;  // Salva apenas os valores máximos
      } else if (sample < signalMin) {
        signalMin = sample;  // Salva apenas os valores mínimos
      }
    }
  }
  peakToPeak = signalMax - signalMin; // Máximo - Mínimo = Amplitude pico a pico
  double volts = (peakToPeak * 3.0) / 1024; // Converte para um valor de tensao aproximado
  voltsTotal += volts;
  }

  voltsTotal = voltsTotal/10;
  Serial.println("(OK)");
  if (voltsTotal <= 1000) { //Filtra possíveis valores residuais 
    float value = mapfloat(voltsTotal, 0.00, 3.00, 37.00, 82.00);
    return value; //Retorna o valor convertido para dB
  } else {
    return 82; 
  }

}

/*Leitura de umidade e temperatura*/
float readDHT22() {
  Serial.println("Iniciando o DHT22...");
  dht.begin(); //Inicializar DHT22.
  Serial.println("DHT22 iniciado!");

  
  //DHT22 - Temperatura e Umidade.
  Serial.println("Lendo temperatura e umidade.");
  temp = dht.readTemperature(); //Ler temperatura - DHT22.
  umid = dht.readHumidity(); //Ler umidade - DHT22.
  Serial.println("(OK)");
  
}


/*Leitura de TVOC e eCO2*/
float readCCS811() {
  //Inicializar sensor CCS811.
  Serial.println("Iniciando o CCS811...");
  if (!ccs.begin()) {
    Serial.println("CCS811 não foi iniciado!");
  } else {
    Serial.println("CCS811 iniciado!");
  }
  Serial.println("Aquecendo CCS811...");
  eco2 = 0;
  eco2Sum = 0;
  vocSum = 0;
  voc = 0;
  Serial.println("Lendo TVOC...");
  for (int i = 0; i < 5; i++) {
    if (ccs.available()) {
      if (!ccs.readData()) {
        eco2 = ccs.geteCO2(); //Ler eCO2 - CCS811.
        voc = ccs.getTVOC(); //Ler TVOC - CCS811.
        vocSum += voc;
        eco2Sum += eco2;
      } else {
        Serial.println("Erro de leitura CCS811!");

      }
    }
    delayTimes(1);
  }
  //Media dos valores...
  eco2 = eco2Sum / 5;
  voc = vocSum / 5;

  if (eco2 > 10000 || voc > 10000) {
    eco2 = 400;
    voc = 0;
  }

  Serial.println("(OK)");
}

/*Faz o envio dos dados para o AirServer.*/
void sendToAirServer(){
  if (!client.connect("server01.matsoftwares.com.br", 1883)) {
    Serial.println("Conexao socket falhou!");
    return;
  }
  if (receiver){
  
    String blob;
    blob = NVS.getString("blob");

    for (int i = 0; i < maxRecords; i++){

      delay(1000);
      Serial.println("Enviando pacote " + String(getValue(blob, '/', i)) + " recebido via ESP-NOW para conexao socket.");
      client.print(String(getValue(blob, '/', i) + "\n"));
  
    }
    NVS.setInt("blobFull",0);
    client.stop();

  } else {

    client.print("INSERT " + String(temp, 2) + " " + String(umid, 2) + " " + String(eco2,2) + " " + String(voc, 2) + " " + String(valorCO2) + " " + String(dbLevel) + " " + String(lux) + " " +  String(AIRPURE_ID) + "\n");
    delay(1000);
    client.stop();
  }
  

  Serial.println("Conexao socket enviou os dados!");
}

/*Faz o envio dos dados para o AirServer.*/
void sendToAirServer(String resposta){
  if (!client.connect("server01.matsoftwares.com.br", 1883)) {
    Serial.println("Conexao socket falhou!");
    return;
  }
  

  client.print(resposta);
  delay(1000);
  client.stop();
  
  

  Serial.println("Conexao socket enviou os dados!");
}

/*Faz o envio dos dados para o Google Sheets.*/
void sendToSheets(){
  Serial.println("Fazendo o envio para o Google Sheets.");
  sendData(
      String(
          "Temperatura=" + String(temp, 2) + "&Umidade="
              + String(umid, 2) + "&eCO2=" + String(eco2, 2)
              + "&TVOC=" + String(voc, 2) + "&CO2="
              + String(valorCO2) + "&Lux=" + String(lux, 5)
              + "&Ruido=" + String(dbLevel, 2) + "&Alarme="
              + String(highCO2, 2) + "&ID=" + String(AIRPURE_ID)
              + "&V_FIRMWARE=" + String(V_FIRMWARE)));
  Serial.println("Envio executado. Um novo envio será feito em um minuto.");
}

/*Leitura dos sensores.*/
void readSensors() {

  Serial.println("Iniciando leitura dos sensores.");
    
  valorCO2 = leituraGas(); //Concentração de CO2 - MH-Z14A.

  readCCS811(); //Leitura do CCS811

  readDHT22();  //Leitura do DHT22

  dbLevel = readDb();//MAX9814 - Ruído

  readLux();  //Leitura do BH1750

}


/*Leitura e publicação dos dados para o ThingSpeak.*/
void mqttpublish() {

  init_WiFi();  //Inicializa o WiFi
  Serial.println("Wifi conectado com sucesso!");
  
  /*Faz o envio dos dados para o ThingSpeak*/
  sendToThingSpeak();


}

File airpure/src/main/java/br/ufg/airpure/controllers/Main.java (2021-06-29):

package br.ufg.airpure.controllers;
import java.sql.Connection;
import java.sql.DatabaseMetaData;
import java.sql.Statement;
import java.text.SimpleDateFormat;
import java.util.Date;
import javax.faces.bean.ManagedBean;
import javax.faces.bean.RequestScoped;
import javax.xml.rpc.holders.StringHolder;
@RequestScoped
@ManagedBean
public class Main extends Thread {

    public static Connection db;        
    public static Statement sql;      
    public static DatabaseMetaData dbmd;    

    static String SVNRevision = " V.244 ";
    static String username = "postgres";
    static String password = "10052019";
    static String database1 = "";
    static Integer TempoCiclo = 10;
    static StringHolder db1 = new StringHolder();

    public String getSVNRevision() {
        Date data = new Date(System.currentTimeMillis()); 
        SimpleDateFormat formatarDate = new SimpleDateFormat("dd/MM/yyyy"); 
        return SVNRevision + " | " + formatarDate.format(data);
    }


    public static void main(String args[]) {
        Connection db;   
        Statement sql;     
        DatabaseMetaData dbmd;     

        BD basedados;
        basedados = new BD();
        database1 = "" + db1.value;
        if (!database1.equals("null")) {
            while (!basedados.ConectarBD());
        }
    }
}

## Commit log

2020-11-21 Alterando o código para troca do sensor DHT11 para DHT22. Os pinos permanecem os mesmos.
2020-11-21 Implementando o sensor de luminosidade BH1750. A sua conexão é direta com o i2c.
2020-11-21 Incluindo as bibliotecas para o sensor BH1750.
2020-11-21 Implementando o sensor de ruído MAX9814.
2020-11-22 Tabela de conexões (Possivelmente com erros).
2020-11-22 Adicionando os arquivos do diagrama de ligações e projeto do photoshop referente ao diagrama.
2020-11-22 Adicionando o canal do thingspeak para o Airpure #1
2020-11-22 Atualizando tabela de conexões.
2020-11-22 Acrescentando um tutorial de Construção do AirPure.
2020-11-22 Adicionando o código para os três AirPure's iniciais.
2020-11-22 Acrescentando a tabela de conexões atualizada.
2020-11-22 Correção de um nome.
2020-11-29 Tentando resolver o problema entre os dois sensores CCS811 e BH1750.
    [air_pure.ino]
2020-11-29 Trocando a porta analógica do sensor visto que as portas ADC2 não funcionam quando o wi-fi está ativo.
2020-11-29 Atualizando a tabela de conexões.
2020-11-29 Atualizando esquemático de ligação.
2020-11-29 Atualizando o esquemático de ligação.
2020-11-29 Correções para o correto funcionamento do código. Wifi-manager implementado.
2020-11-29 Correção de um erro de ligação.
2020-11-29 Correção de esquemático.
2020-12-06 Incluindo envio de alarme quando o valor de CO2 ultrapassar 1000ppm.
2020-12-08 Incluindo código base para o protótipo da interface WEB.
2020-12-10 Criando o diretório para os arquivos do website.
2020-12-11 Mudando a biblioteca do CCS811 por motivos de alguns problemas.
    [air_pure.ino]
2020-12-20 Adicionando a landing page básica.
2020-12-29 Corrigindo a inconsistência na tentativa de se conectar à uma rede wifi.
    [air_pure.ino]
2020-12-29 Landing page...
2021-01-12 Corrigindo erro de conexão.
    [air_pure.ino]
2021-01-13 Incluindo valor de CO2 no aviso do telegram.
2021-01-20 Incluindo OTA para gravação via internet, sem necessidade de cabo serial.
2021-01-20 Bump next from 9.5.3 to 9.5.4 in /Landing Page
    Bumps [next](https://github.com/vercel/next.js) from 9.5.3 to 9.5.4.
    - [Release notes](https://github.com/vercel/next.js/releases)
    - [Changelog](https://github.com/vercel/next.js/blob/canary/release.js)
    - [Commits](https://github.com/vercel/next.js/compare/v9.5.3...v9.5.4)
2021-02-11 Resolvendo problemas sem sentido....
    [air_pure.ino]
2021-02-11 Evitando que o valor do CCS811 ultrapasse o limite permitido.
2021-02-12 Corrigindo um erro com o envio ao telegram.
    [air_pure.ino]
2021-02-16 Incluindo gerber da PCB
2021-02-21 Desenvolvimento case
    [OBJ_PCB_AIRPURE.obj, PCB_AIRPURE_2021-02-21.dxf, airpure_case.blend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]
2021-02-22 Enviando informação de versal de firmware para o google sheets
2021-03-02 Incluindo codigo contador de pessoas
2021-03-10 Pcb contador de pessoas.
2021-03-12 Case 3D
    [OBJ_PCB_AIRPURE.obj, OBJ_PCB_AIRPURE.stl, PCB_AIRPURE_2021-03-10.obj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]
2021-03-18 Protótipo de concentrador de pacotes com inteligência artificial.
2021-03-24 Alterando contador de pessoas.
2021-03-30 PWM no pino do LED e finalizando contador de pessoas.
2021-04-03 Incluindo conexão socket para envio para o airserver.
2021-04-03 Atualizando portas contador de pessoas e arquivos blender.
    [BASE_AIRPURE.stl, FINAL_OK.blend, TAMPASEMLOGO.stl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]
2021-04-06 Trabalhando no led.
2021-04-13 Melhorando a medida de ruido.
2021-04-18 Organizando arquivos.
    [BASE_AIRPURE.stl, COMPLETO.stl, COMPLETO2.stl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]
2021-04-19 Incluindo modelo de gráficos.
2021-04-19 AirServer. Envio de registros ao banco de dados.
2021-04-19 Corrigindo um problema ao enviar ao banco.
    [air_pure.ino, globaldef.h]
2021-04-21 Refresh automatico de informações.
2021-04-25 Corrigindo funcionamento do led quando procura wifi.
    [utils.ino]
2021-04-25 Corrigindo valor maximo CO2
    [sensors.ino]
2021-04-25 Atualização arquivos SASO
    Alteração da Home e do período de leitura dos dados em tempo real.
2021-04-27 Atualização SASO
    Atualização da Home SASO e criação de arquivos intermediários.
2021-04-27 Case final versão 1.
    [Base.stl, FINAL_OK.blend, Tampa.stl]
2021-04-27 Incluindo modelo do banco de dados.
2021-04-29 Incluindo implementação de notificações.
2021-04-30 Incluindo query para requisição dos últimos dados para envio das notificações.
2021-05-01 Implementando notificações. Falta definir critério de envio (diário, instantâneo...)
2021-05-01 Incluindo cadastro de dispositivos.
2021-05-03 Resolvendo um problema de cast.
2021-05-03 Implementando cadastro de manutenções.
2021-05-03 Arrumando tela de login.
2021-05-06 Atualização Notificações
    Inclusão do Form, apenas front, para notificação.
2021-05-08 Incluindo botão para visualização sem login.
2021-05-08 Atualizando link landingpage.
2021-05-12 Cadastros de ambientes, dispositivos,A.C....
2021-05-12 Bump chart.js from 2.9.3 to 2.9.4 in /Landing Page
    Bumps [chart.js](https://github.com/chartjs/Chart.js) from 2.9.3 to 2.9.4.
    - [Release notes](https://github.com/chartjs/Chart.js/releases)
    - [Commits](https://github.com/chartjs/Chart.js/compare/v2.9.3...v2.9.4)
2021-05-19 Consulta
    Finalização do back-end da classe de consulta aos dados.
2021-05-26 Trocando a quantidade de colunas da página de detalhes.
2021-05-30 Retirando classificação de IA visto sua não utilização.
2021-06-06 Incluindo página para o questionário.
2021-06-08 fix (airServer): Atualizando a unidade do TVOC para uG/m^3.
2021-06-08 fix (range): Alterações de nome de parâmetro TVOC, unidade de medida, padronização de cores.
2021-06-08 fix (error): Retirando funcionalidades não utilizadas.
    [air_pure.ino, sensors.ino, utils.ino]
2021-06-12 fix (espnow): maximo de pacotes.
    [globaldef.h, utils.ino]
2021-06-12 fix (unidade): corrigindo unidade de medida do CO2.
2021-06-14 fix (range): mudando parametro de compostos.
2021-06-18 fix (graficos): diminuindo quantidade de amostras no intervalo inicial.
2021-06-29 fix (email): corrigindo query sql.
    [Main.java]
